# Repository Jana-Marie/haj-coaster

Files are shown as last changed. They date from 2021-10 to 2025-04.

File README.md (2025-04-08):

# haj-coaster

A sharky and colourful coaster glowing in pride for you~.

It consists of a stack of three circuit boards, sandwhiched together. There is a STM32F072, a LED driver and plenty LEDs on the baseboard, cutouts on the midboards to hide the components in, and a mask frontboard that shows the artwork. The LEDs are not all simple RGB ones, but a set of single color LEDs for the stars, carefully selected to represent the diversity in color on a night sky. For the girl on the left side, each LED spot consists of 5 single LEDs, RGB + Pink + Cyan, allowing one to expand the typical RGB range with opically pleasant cyan tones (for the shark and drink) and pink tones (e.g. for the skin, shark and drink).
There is also a NTC within the stack, I intended to change the sharks colour from cyan to pink following the coasters temperature. A warm drink would tint the shark pink, a cold one cyan. However, I never dared to place a drink on it, it's just to cute to hide it behind some glass or mug 🥺

<table>
  <tbody>
    <tr>
      <td colspan="2">
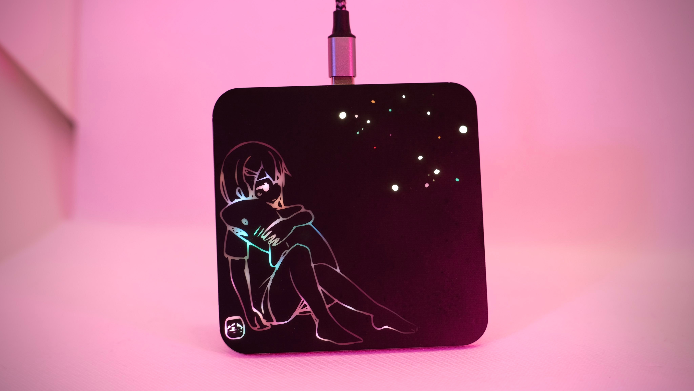
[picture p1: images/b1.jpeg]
        
      </td>
    </tr>
    <tr>
      <td>
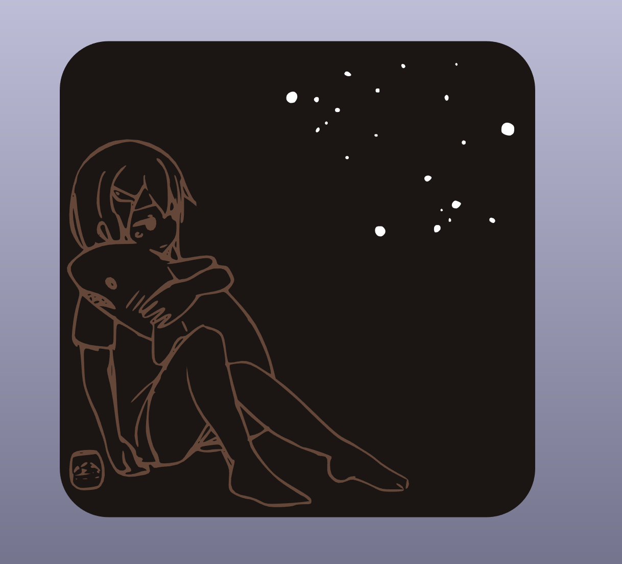
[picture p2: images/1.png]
        
      </td>
      <td>
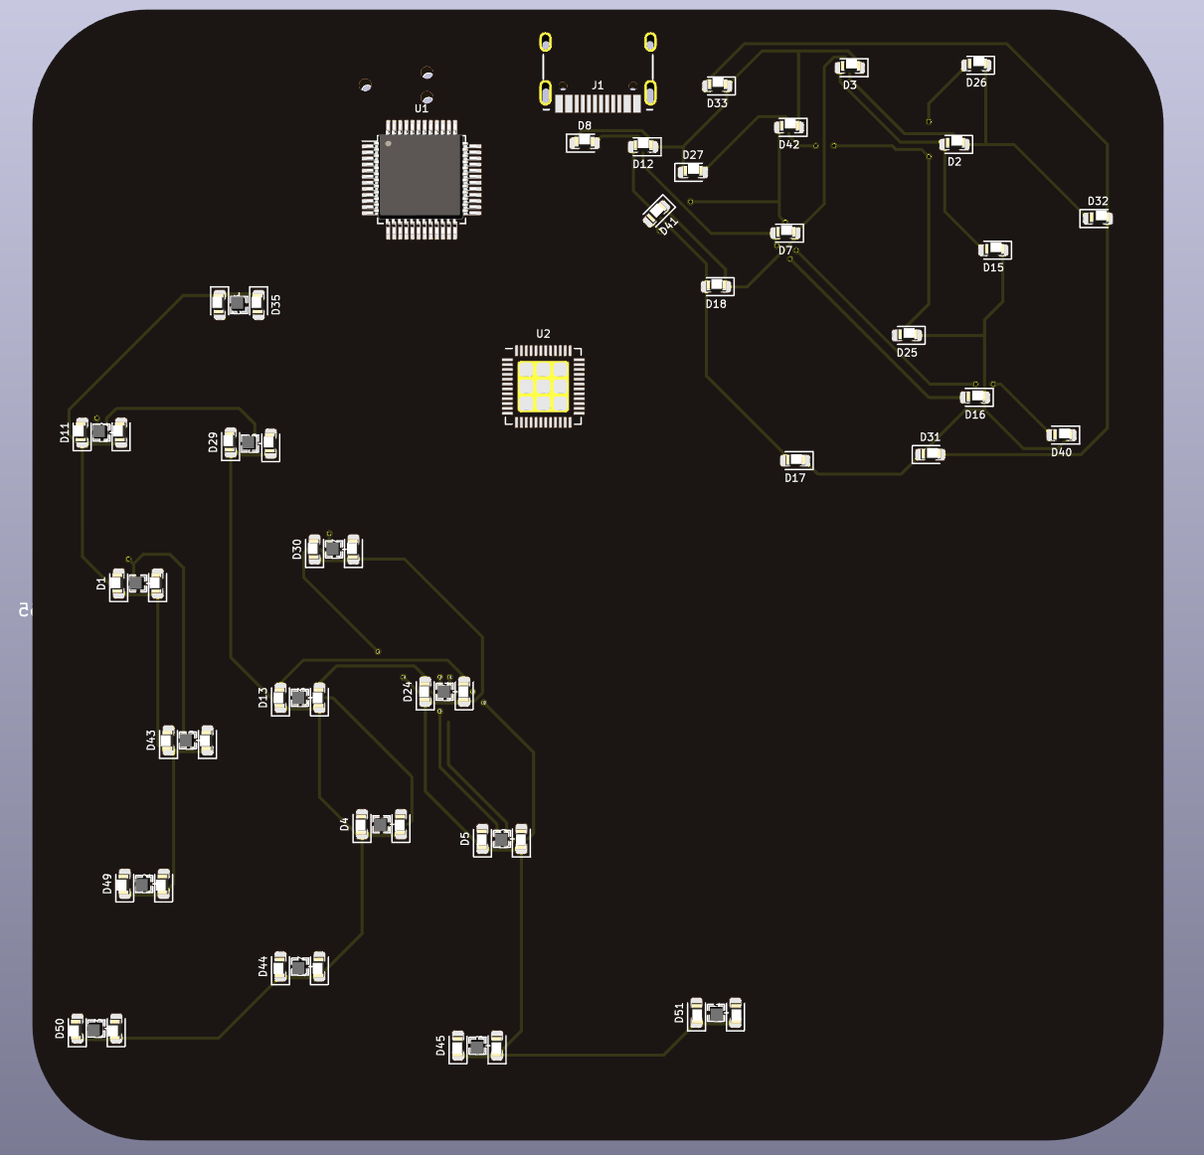
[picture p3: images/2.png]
        
      </td>
    </tr>
    <tr>
      <td colspan="2">
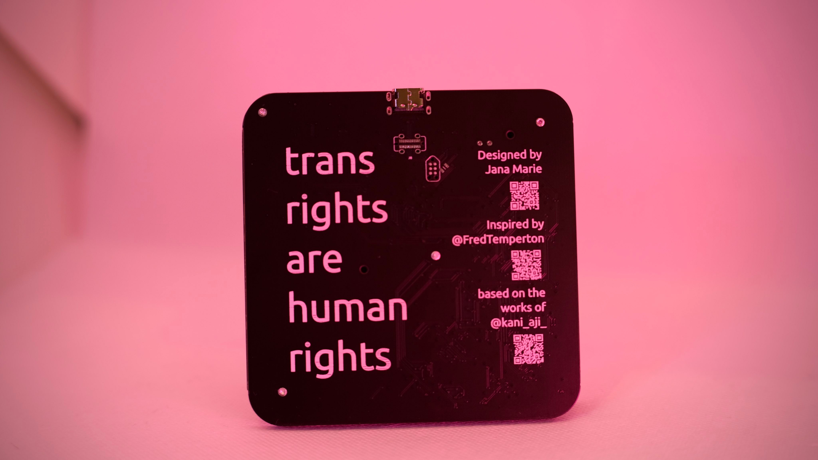
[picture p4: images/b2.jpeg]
        
      </td>
    </tr>
    <tr>
      <td>
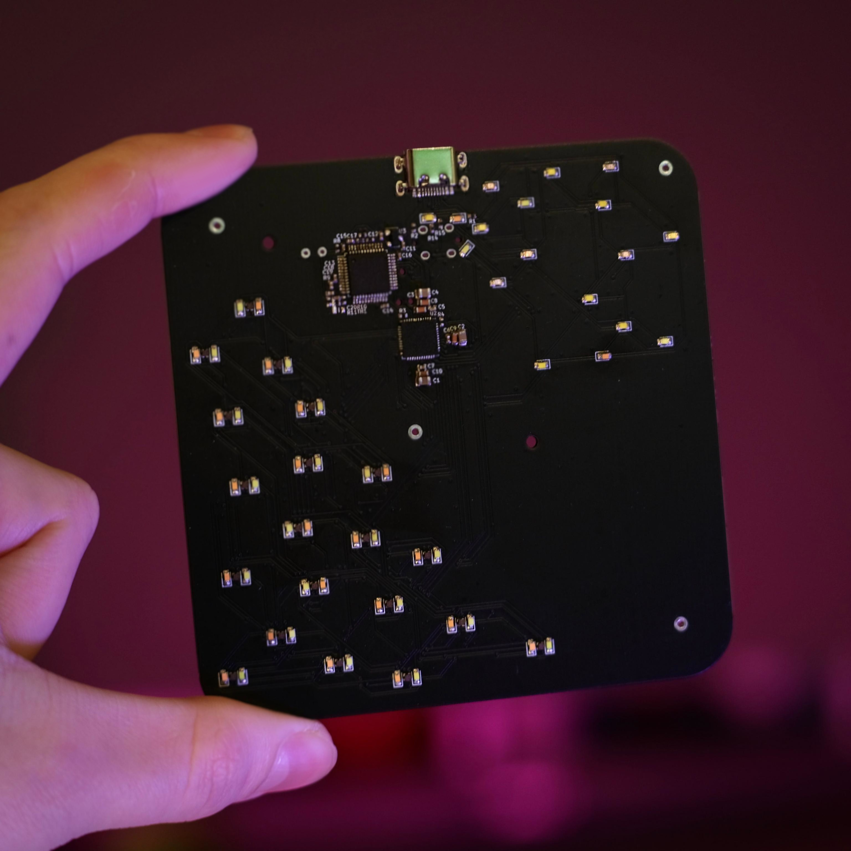
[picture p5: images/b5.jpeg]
        
      </td>
      <td>
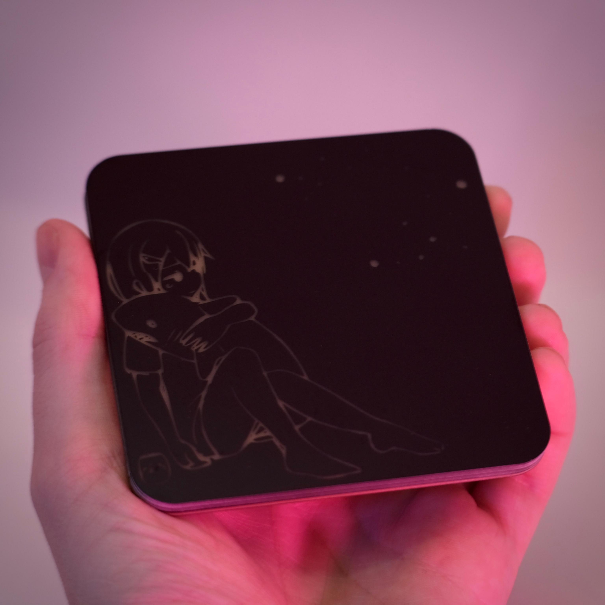
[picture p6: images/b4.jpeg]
        
      </td>
    </tr>
    <tr>
      <td colspan="2">
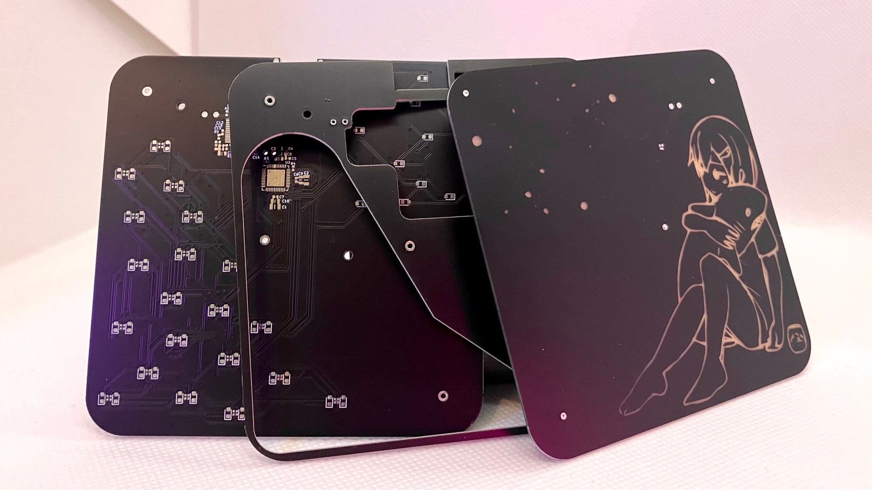
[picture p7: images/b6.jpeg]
        
      </td>
    </tr>
  </tbody>
</table>

---

### Schematic

(https://github.com/Jana-Marie/haj-coaster/blob/main/coaster_backboard/schematic.pdf)[schematic.pdf]

---

Thank you [かにあじ](https://void-aquarium.com/) for allowing me to use your fantastic artwork for this project! ありがとうございます!

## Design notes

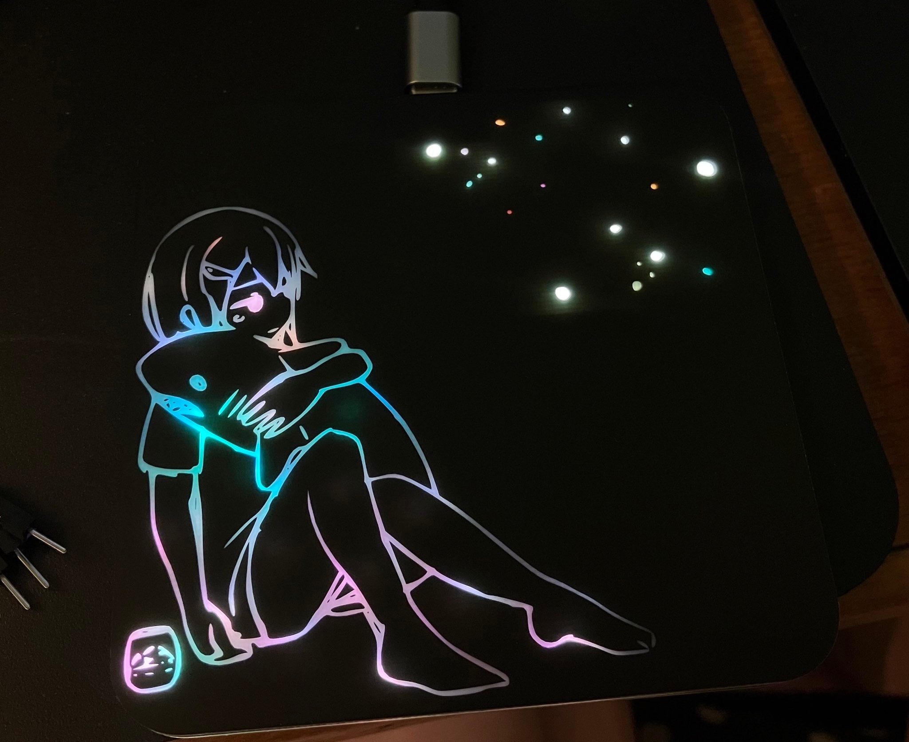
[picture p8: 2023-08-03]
images/f.jpeg

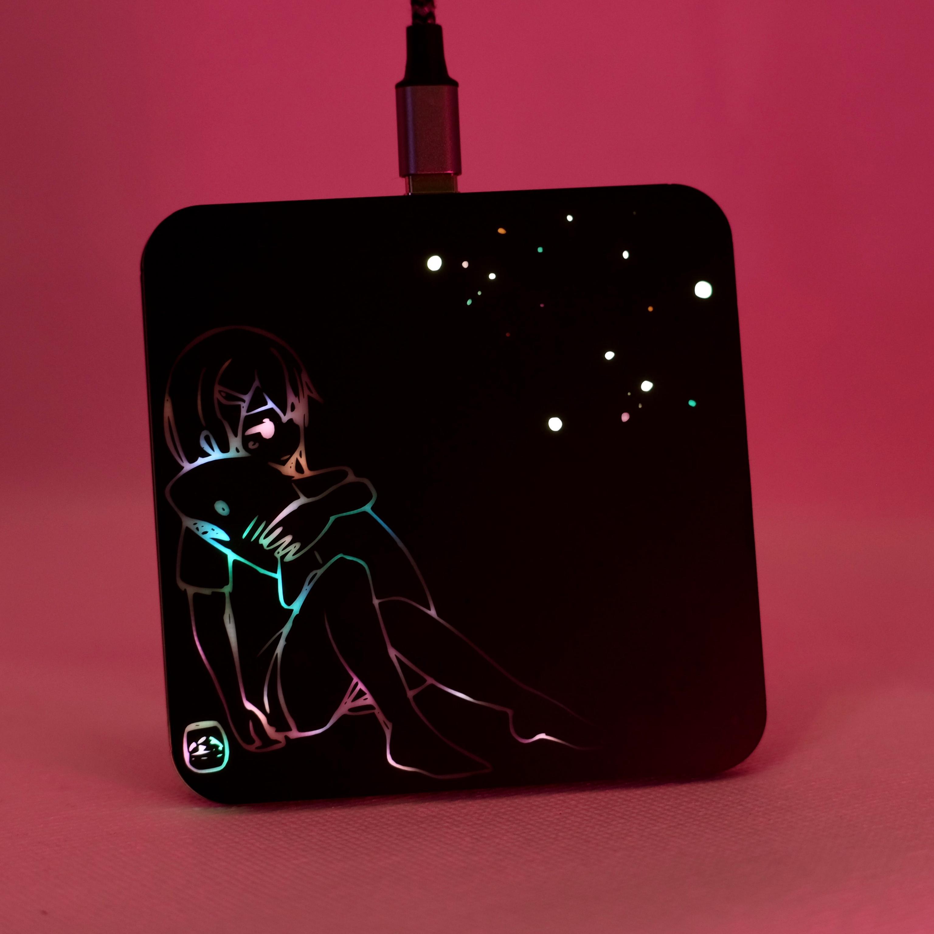
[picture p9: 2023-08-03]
images/b3.jpeg

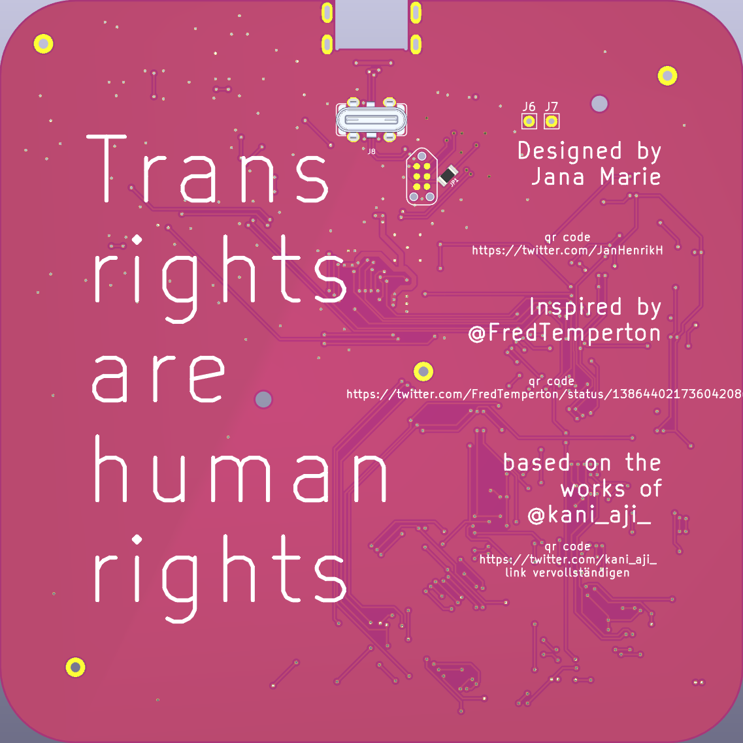
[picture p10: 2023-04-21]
coaster_backboard/assets/Screenshot from 2021-12-30 00-20-10.png

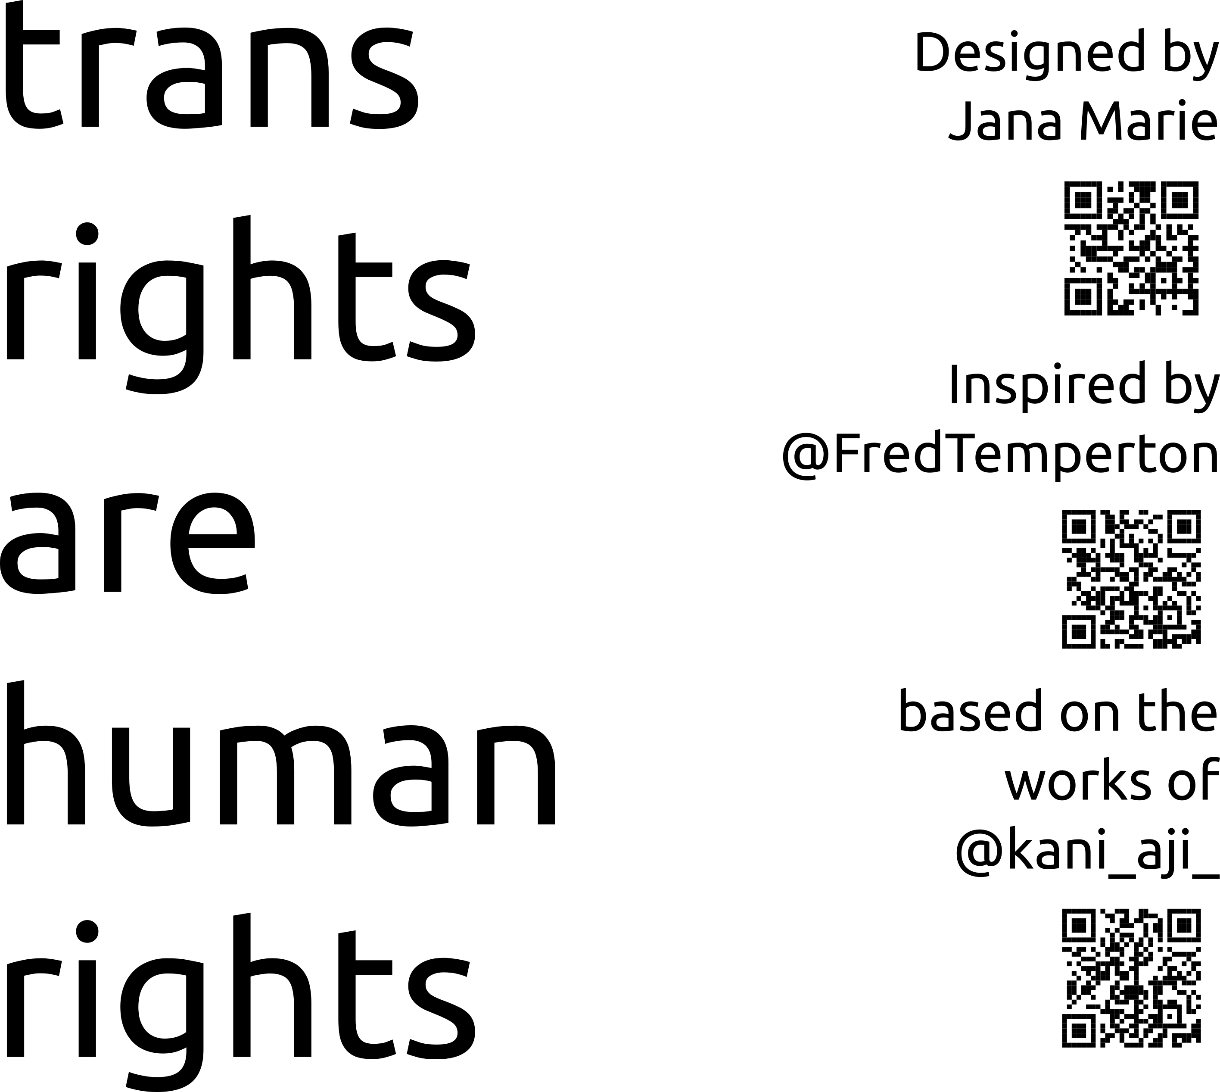
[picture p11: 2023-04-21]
coaster_backboard/assets/text_all.png

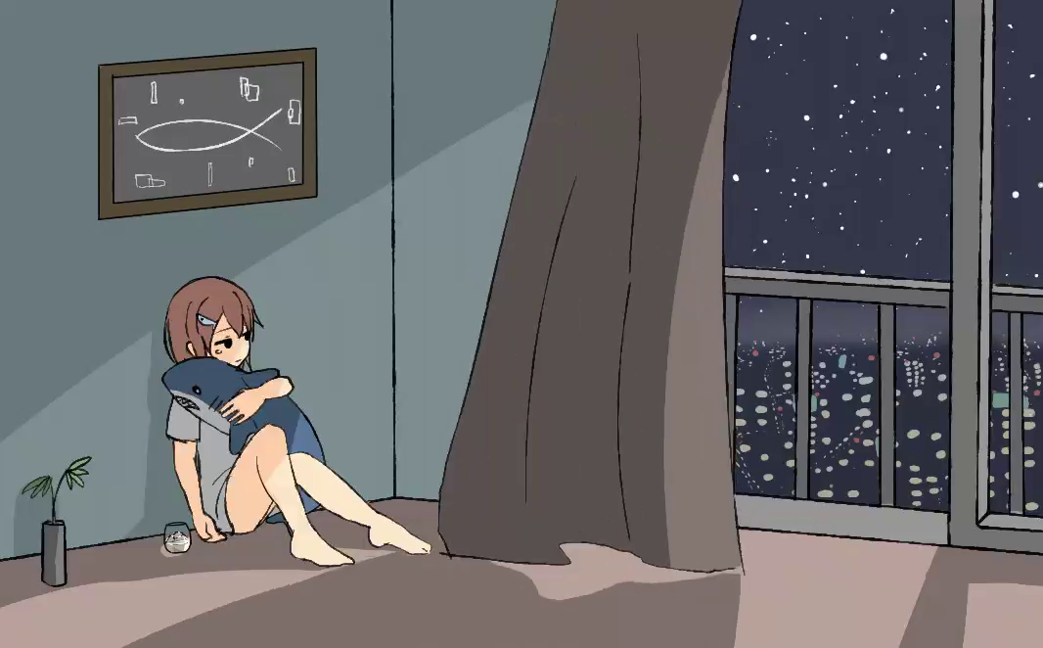
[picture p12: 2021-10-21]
artwork/out6.png

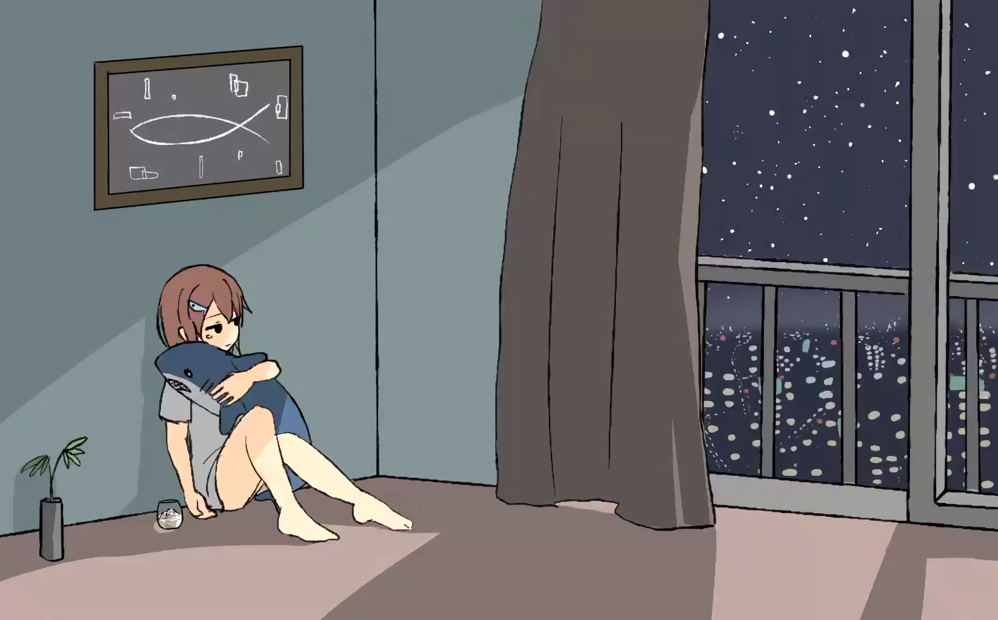
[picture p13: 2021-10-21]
artwork/out1_x4.png

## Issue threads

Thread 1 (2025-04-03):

Actual LEDs used

TyberiusPrime, 2025-04-03:
Gorgeous design, now you made me reinstall kicad after I had kicked the PCB habit for a good long time.

Currently struggling with picking the right LEDs over at JCLPCB.

Would you mind documenting which ones you used exactly?
I'm so unversed in kicad, it's only telling me the footprint and 'pink'.

Jana-Marie, 2025-04-08:
Hey, thank you! And I'm glad that you are back to KiCAD! :3

Let's see, something like this:

Pink: https://jlcpcb.com/partdetail/Xinglight-XL_1608UPC06/C2977076
Blue (Cyan): https://jlcpcb.com/partdetail/Meihua-MHT192WDTICE/C389522
RGB: https://jlcpcb.com/partdetail/169447-FC_B1010RGBTHG/C158099

These are all for the left side of the board, where the artwork of the girl and the shark is. For the starred sky I just used whatever I liked and I encourage you to do the same! Make it your board! :3

If you want a reference or copy my mostly random dispersion of colors, you can check this image for reference:

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

I think I used:

8 white LEDs: https://jlcpcb.com/partdetail/85434-NCD0603W1/C84265
3 Cyan LEDs: https://jlcpcb.com/partdetail/Meihua-MHT192WDTICE/C389522
2 amber/Yellow LEDs: https://jlcpcb.com/partdetail/Inolux-INS63AT5A/C5656657
                     or https://jlcpcb.com/partdetail/85438-NCD0603O1/C84269
2 pink LEDs: https://jlcpcb.com/partdetail/Xinglight-XL_1608UPC06/C2977076

But really, feel free to mix this up or even let them out on JLCs assembly and manually put them on the boards, make every board different. I really liked thinking about my favorite images of the Milky Way and thinking on how to replicate the lovely colours it can produce. This is also why I used discrete colours/wavelengths instead of RGB leds here.

Sorry for the late answer btw, hope you can get it manufactured!

Best
Jana

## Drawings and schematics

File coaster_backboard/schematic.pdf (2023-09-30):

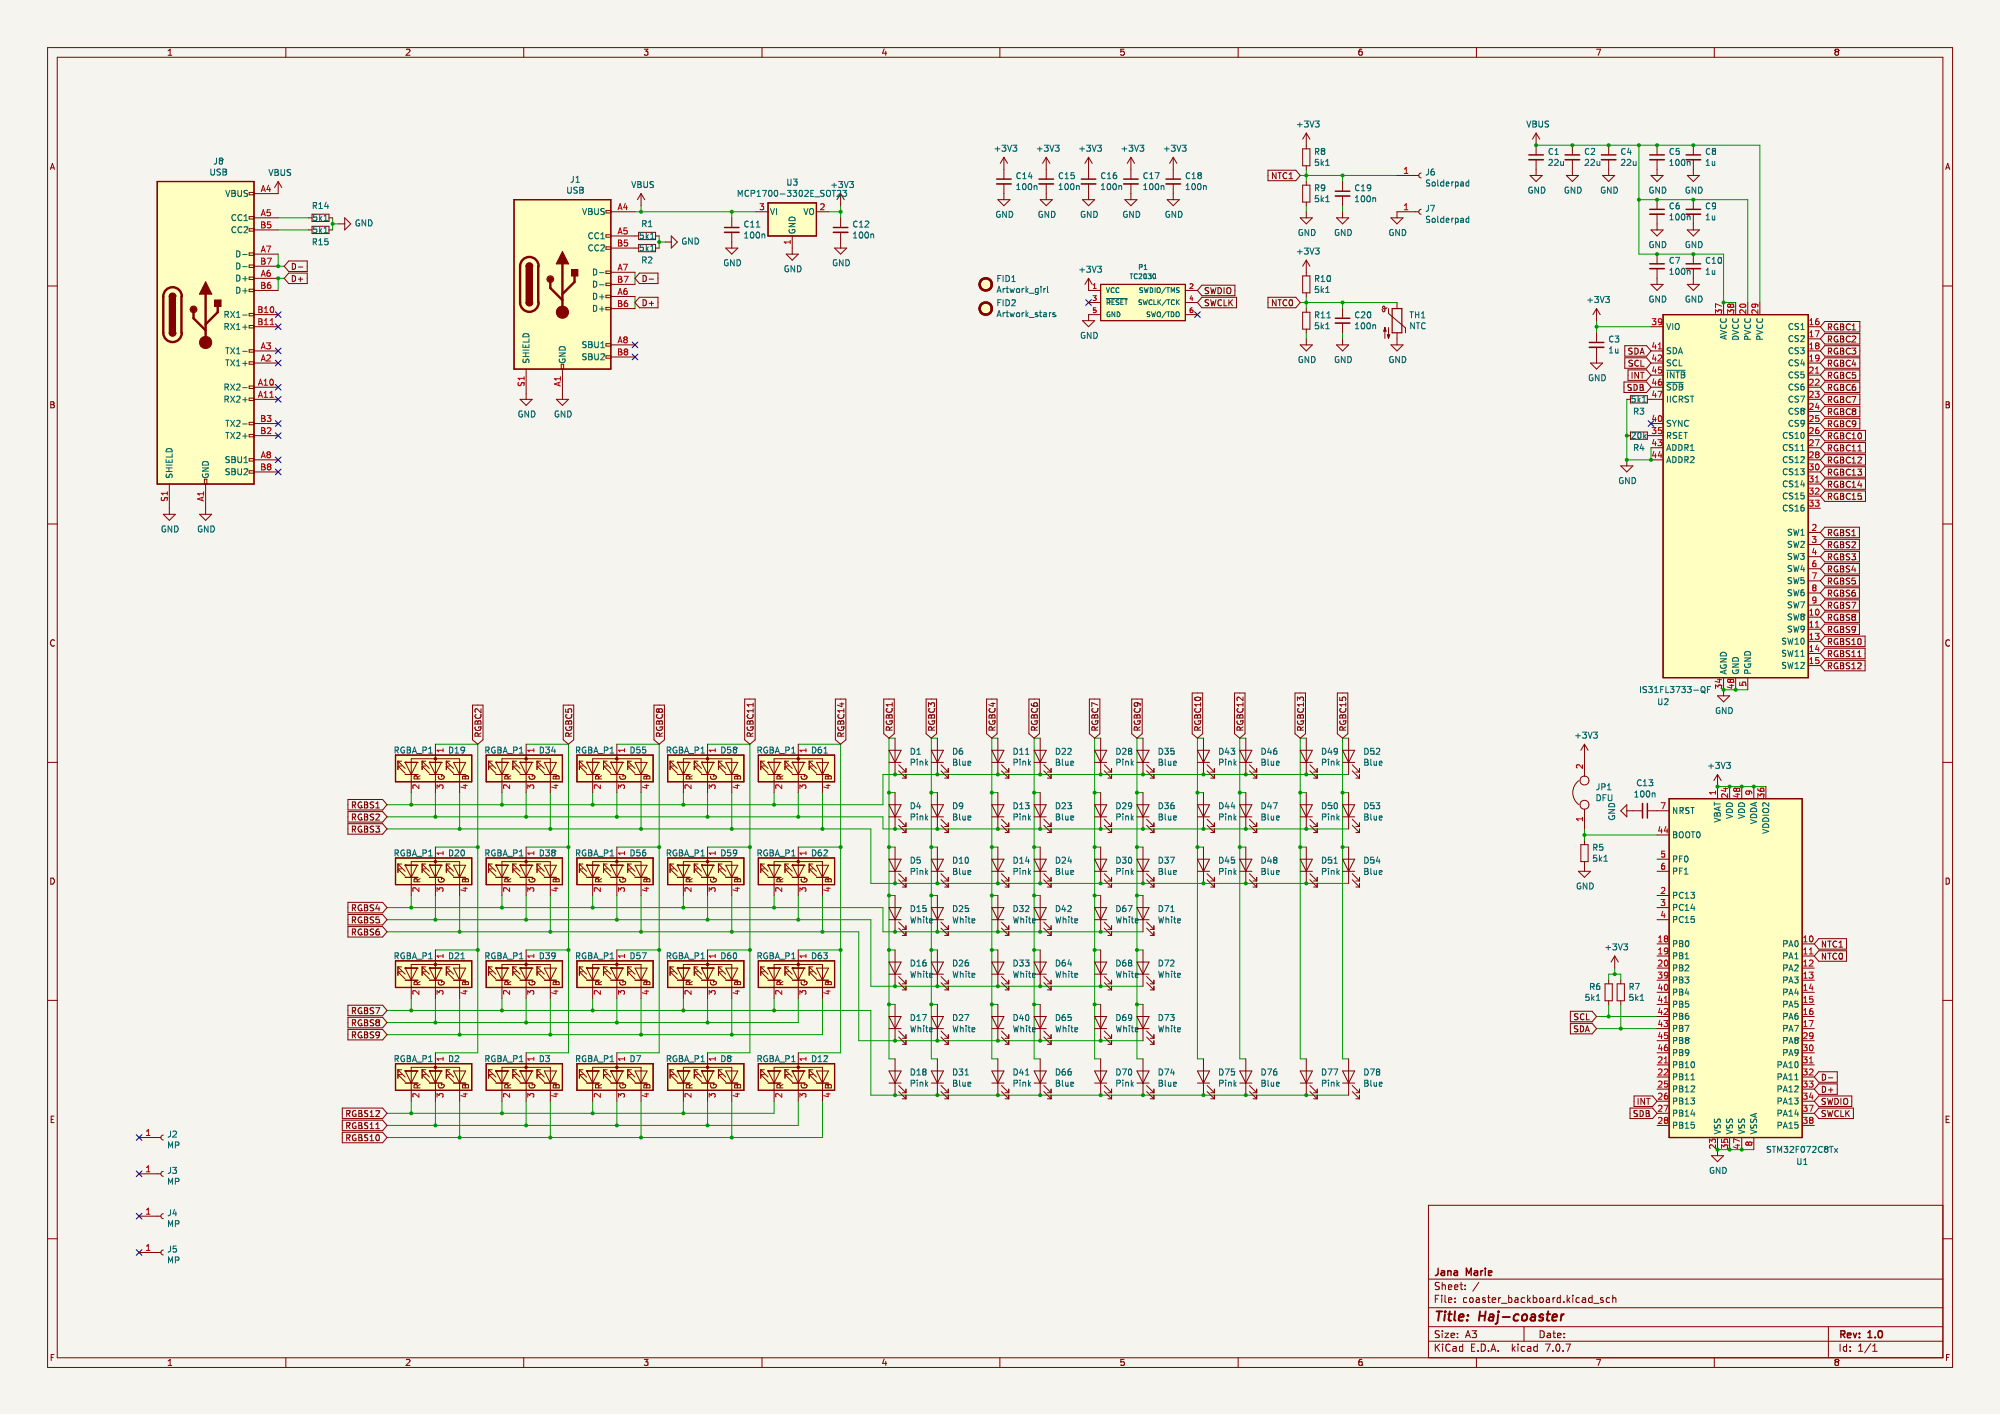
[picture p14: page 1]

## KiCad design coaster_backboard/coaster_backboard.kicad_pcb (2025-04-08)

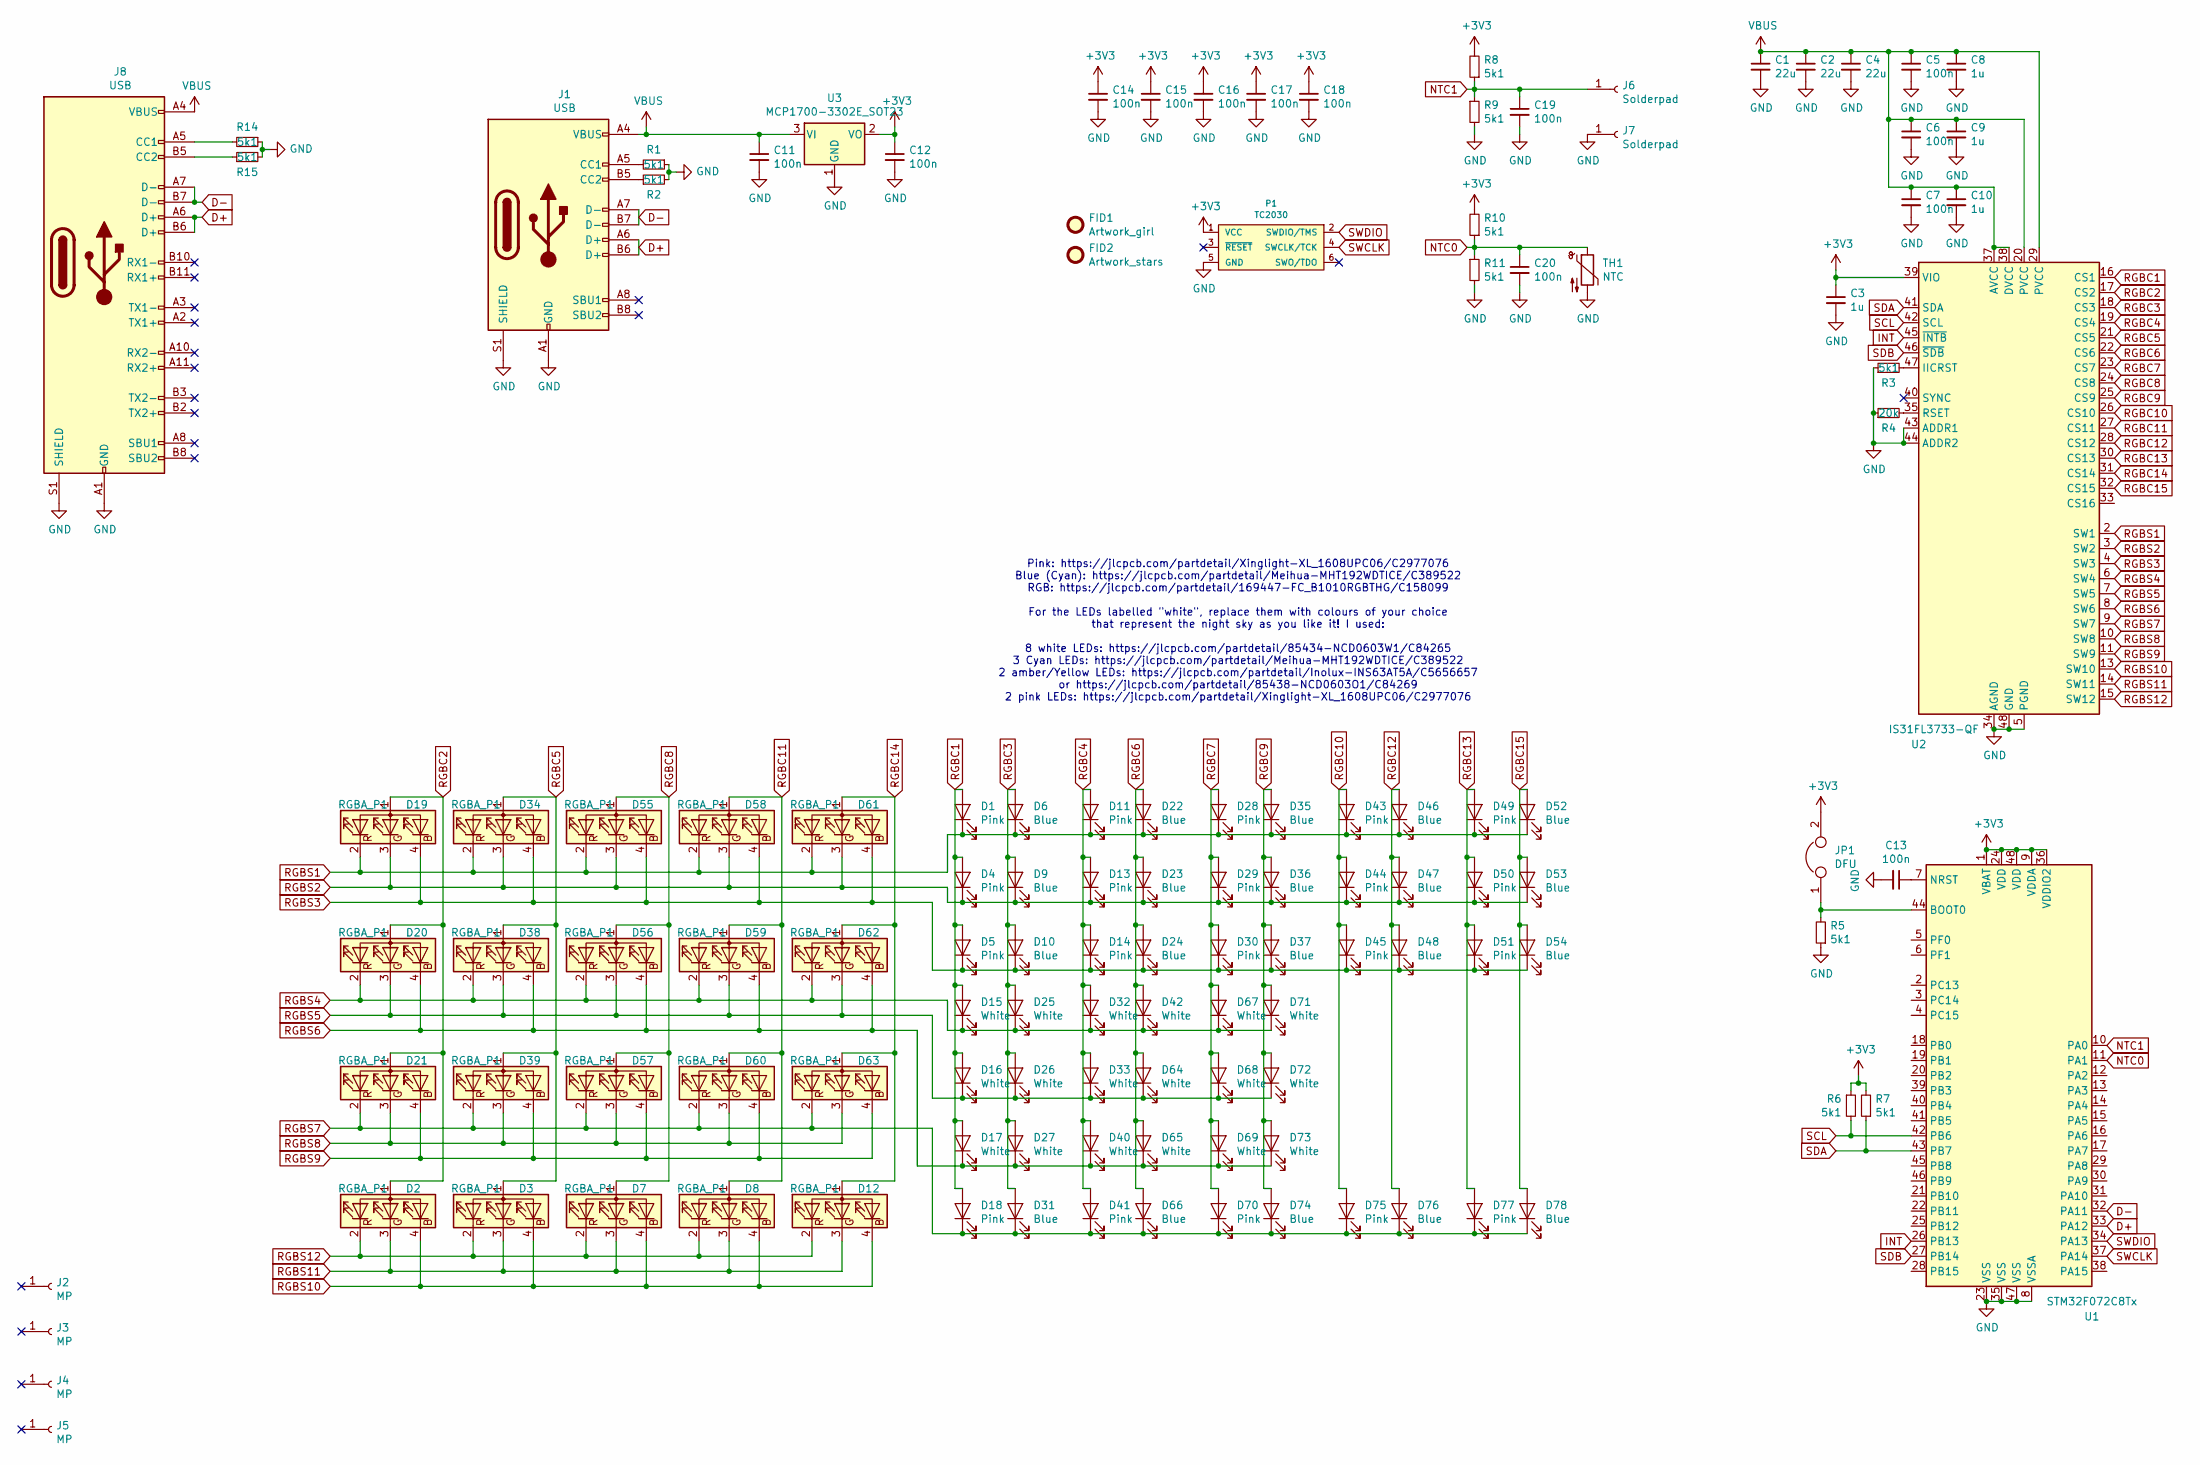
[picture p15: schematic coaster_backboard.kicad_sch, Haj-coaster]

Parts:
C1, C2, C4: 22u; C_0805
C3, C8, C9, C10: 1u; C_0603
C5, C6, C7, C11, C12, C13, C14, C15, C16, C17, C18, C19, C20: 100n; C_0402
D1, D4, D5, D11, D13, D14, D18, D28, D29, D30, D41, D43, D44, D45, D49, D50, D51, D70, D75, D77: Pink; LED_0603_1608Metric
D2, D3, D7, D8, D12, D19, D20, D21, D34, D38, D39, D55, D56, D57, D58, D59, D60, D61, D62, D63: RGBA_P1; FC-B1010RGBT-HG
D6, D9, D10, D22, D23, D24, D31, D35, D36, D37, D46, D47, D48, D52, D53, D54, D66, D74, D76, D78: Blue; LED_0603_1608Metric
D15, D16, D17, D25, D26, D27, D32, D33, D40, D42, D64, D65, D67, D68, D69, D71, D72, D73: White; LED_0603_1608Metric
FID1: Artwork_girl; shark_girl_kani_aji_
FID2: Artwork_stars; stars_kani_aji_
J1: USB; USB-C 16Pin InBoard
J2, J3, J4, J5: MP; Pin_D1.0mm_L10.0mm_LooseFit
J6, J7: Solderpad; Pin_D0.7mm_L6.5mm_W1.8mm_FlatFork
J8: USB; 918-418K2022Y40004
JP1: DFU; R_0805
P1: TC2030
R1, R2, R3, R5, R6, R7, R8, R9, R10, R11, R14, R15: 5k1; R_0402
R4: 20k; R_0402
TH1: NTC; R_0603
U1: STM32F072C8Tx; LQFP-48_7x7mm_P0.5mm
U2: IS31FL3733-QF; QFN-48-1EP_6x6mm_P0.4mm_EP4.2x4.2mm
U3: MCP1700-3302E_SOT23; SOT-23

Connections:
+3V3: C3.1, C12.1, C14.1, C15.1, C16.1, C17.1, C18.1, JP1.2, P1.1 (VCC), R6.1, R7.2, R8.2, R10.2, U1.1 (VBAT), U1.9 (VDDA), U1.24 (VDD), U1.36 (VDDIO2), U1.48 (VDD), U2.39 (VIO), U3.2 (VO)
D+: J1.A6 (D+), J1.B6 (D+), J8.A6 (D+), J8.B6 (D+), U1.33 (PA12)
D-: J1.A7 (D-), J1.B7 (D-), J8.A7 (D-), J8.B7 (D-), U1.32 (PA11)
GND: C1.2, C2.2, C3.2, C4.2, C5.2, C6.2, C7.2, C8.2, C9.2, C10.2, C11.2, C12.2, C13.2, C14.2, C15.2, C16.2, C17.2, C18.2, C19.2, C20.2, J1.A1 (GND), J1.A12 (GND), J1.B1 (GND), J1.B12 (GND), J1.S1 (SHIELD), J7.1, J8.A1 (GND), J8.A12 (GND), J8.B1 (GND), J8.B12 (GND), J8.S1 (SHIELD), P1.5 (GND), R1.1, R2.2, R3.1, R4.1, R5.1, R9.2, R11.2, R14.1, R15.2, TH1.2, U1.8 (VSSA), U1.23 (VSS), U1.35 (VSS), U1.47 (VSS), U2.5 (PGND), U2.12 (PGND), U2.34 (AGND), U2.43 (ADDR1), U2.44 (ADDR2), U2.48 (GND), U2.49 (GND), U3.1 (GND)
INT: U1.26 (PB13), U2.45 (~INTB)
NTC0: C20.1, R10.1, R11.1, TH1.1, U1.11 (PA1)
NTC1: C19.1, J6.1, R8.1, R9.1, U1.10 (PA0)
unnamed: C13.1, U1.7 (NRST)
unnamed: J1.A5 (CC1), R1.2
unnamed: J1.B5 (CC2), R2.1
unnamed: J8.A5 (CC1), R14.2
unnamed: J8.B5 (CC2), R15.1
unnamed: JP1.1, R5.2, U1.44 (BOOT0)
unnamed: R3.2, U2.47 (IICRST)
unnamed: R4.2, U2.35 (RSET)
RGBC1: D1.2 (A), D4.2 (A), D5.2 (A), D15.2 (A), D16.2 (A), D17.2 (A), D18.2 (A), U2.16 (CS1)
RGBC2: D2.1 (A), D19.1 (A), D20.1 (A), D21.1 (A), U2.17 (CS2)
RGBC3: D6.2 (A), D9.2 (A), D10.2 (A), D25.2 (A), D26.2 (A), D27.2 (A), D31.2 (A), U2.18 (CS3)
RGBC4: D11.2 (A), D13.2 (A), D14.2 (A), D32.2 (A), D33.2 (A), D40.2 (A), D41.2 (A), U2.19 (CS4)
RGBC5: D3.1 (A), D34.1 (A), D38.1 (A), D39.1 (A), U2.21 (CS5)
RGBC6: D22.2 (A), D23.2 (A), D24.2 (A), D42.2 (A), D64.2 (A), D65.2 (A), D66.2 (A), U2.22 (CS6)
RGBC7: D28.2 (A), D29.2 (A), D30.2 (A), D67.2 (A), D68.2 (A), D69.2 (A), D70.2 (A), U2.23 (CS7)
RGBC8: D7.1 (A), D55.1 (A), D56.1 (A), D57.1 (A), U2.24 (CS8)
RGBC9: D35.2 (A), D36.2 (A), D37.2 (A), D71.2 (A), D72.2 (A), D73.2 (A), D74.2 (A), U2.25 (CS9)
RGBC10: D43.2 (A), D44.2 (A), D45.2 (A), D75.2 (A), U2.26 (CS10)
RGBC11: D8.1 (A), D58.1 (A), D59.1 (A), D60.1 (A), U2.27 (CS11)
RGBC12: D46.2 (A), D47.2 (A), D48.2 (A), D76.2 (A), U2.28 (CS12)
RGBC13: D49.2 (A), D50.2 (A), D51.2 (A), D77.2 (A), U2.30 (CS13)
RGBC14: D12.1 (A), D61.1 (A), D62.1 (A), D63.1 (A), U2.31 (CS14)
RGBC15: D52.2 (A), D53.2 (A), D54.2 (A), D78.2 (A), U2.32 (CS15)
RGBS1: D1.1 (K), D6.1 (K), D11.1 (K), D19.2 (RK), D22.1 (K), D28.1 (K), D34.2 (RK), D35.1 (K), D43.1 (K), D46.1 (K), D49.1 (K), D52.1 (K), D55.2 (RK), D58.2 (RK), D61.2 (RK), U2.2 (SW1)
RGBS2: D4.1 (K), D9.1 (K), D13.1 (K), D19.3 (GK), D23.1 (K), D29.1 (K), D34.3 (GK), D36.1 (K), D44.1 (K), D47.1 (K), D50.1 (K), D53.1 (K), D55.3 (GK), D58.3 (GK), D61.3 (GK), U2.3 (SW2)
RGBS3: D5.1 (K), D10.1 (K), D14.1 (K), D19.4 (BK), D24.1 (K), D30.1 (K), D34.4 (BK), D37.1 (K), D45.1 (K), D48.1 (K), D51.1 (K), D54.1 (K), D55.4 (BK), D58.4 (BK), D61.4 (BK), U2.4 (SW3)
RGBS4: D15.1 (K), D20.2 (RK), D25.1 (K), D32.1 (K), D38.2 (RK), D42.1 (K), D56.2 (RK), D59.2 (RK), D62.2 (RK), D67.1 (K), D71.1 (K), U2.6 (SW4)
RGBS5: D16.1 (K), D20.3 (GK), D26.1 (K), D33.1 (K), D38.3 (GK), D56.3 (GK), D59.3 (GK), D62.3 (GK), D64.1 (K), D68.1 (K), D72.1 (K), U2.7 (SW5)
RGBS6: D17.1 (K), D20.4 (BK), D27.1 (K), D38.4 (BK), D40.1 (K), D56.4 (BK), D59.4 (BK), D62.4 (BK), D65.1 (K), D69.1 (K), D73.1 (K), U2.8 (SW6)
RGBS7: D18.1 (K), D21.2 (RK), D31.1 (K), D39.2 (RK), D41.1 (K), D57.2 (RK), D60.2 (RK), D63.2 (RK), D66.1 (K), D70.1 (K), D74.1 (K), D75.1 (K), D76.1 (K), D77.1 (K), D78.1 (K), U2.9 (SW7)
RGBS8: D21.3 (GK), D39.3 (GK), D57.3 (GK), D60.3 (GK), D63.3 (GK), U2.10 (SW8)
RGBS9: D21.4 (BK), D39.4 (BK), D57.4 (BK), D60.4 (BK), D63.4 (BK), U2.11 (SW9)
RGBS10: D2.4 (BK), D3.4 (BK), D7.4 (BK), D8.4 (BK), D12.4 (BK), U2.13 (SW10)
RGBS11: D2.3 (GK), D3.3 (GK), D7.3 (GK), D8.3 (GK), D12.3 (GK), U2.14 (SW11)
RGBS12: D2.2 (RK), D3.2 (RK), D7.2 (RK), D8.2 (RK), D12.2 (RK), U2.15 (SW12)
SCL: R6.2, U1.42 (PB6), U2.42 (SCL)
SDA: R7.1, U1.43 (PB7), U2.41 (SDA)
SDB: U1.27 (PB14), U2.46 (~SDB)
SWCLK: P1.4 (SWCLK/TCK), U1.37 (PA14)
SWDIO: P1.2 (SWDIO/TMS), U1.34 (PA13)
VBUS: C1.1, C2.1, C4.1, C5.1, C6.1, C7.1, C8.1, C9.1, C10.1, C11.1, J1.A4 (VBUS), J1.A9 (VBUS), J1.B4 (VBUS), J1.B9 (VBUS), J8.A4 (VBUS), J8.A9 (VBUS), J8.B4 (VBUS), J8.B9 (VBUS), U2.20 (PVCC), U2.29 (PVCC), U2.37 (AVCC), U2.38 (DVCC), U3.3 (VI)

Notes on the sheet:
Pink: https://jlcpcb.com/partdetail/Xinglight-XL_1608UPC06/C2977076 Blue (Cyan): https://jlcpcb.com/partdetail/Meihua-MHT192WDTICE/C389522 RGB: https://jlcpcb.com/partdetail/169447-FC_B1010RGBTHG/C158099 For the LEDs labelled "white", replace them with colours of your choice that represent the nigh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

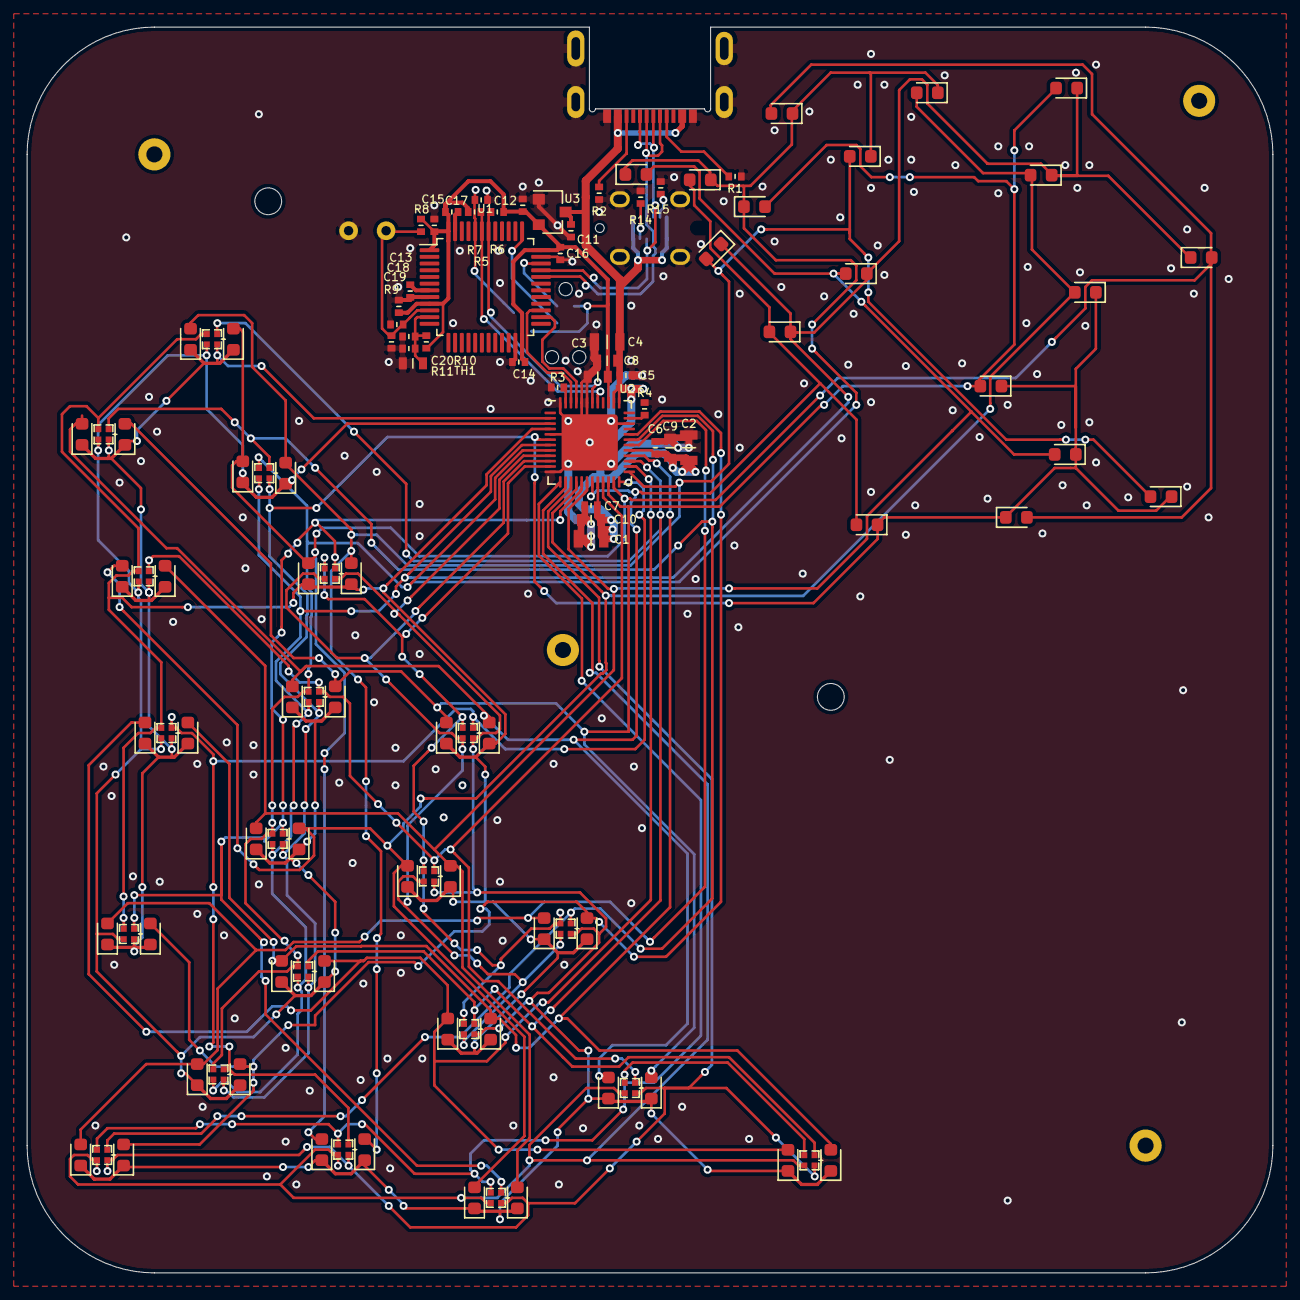
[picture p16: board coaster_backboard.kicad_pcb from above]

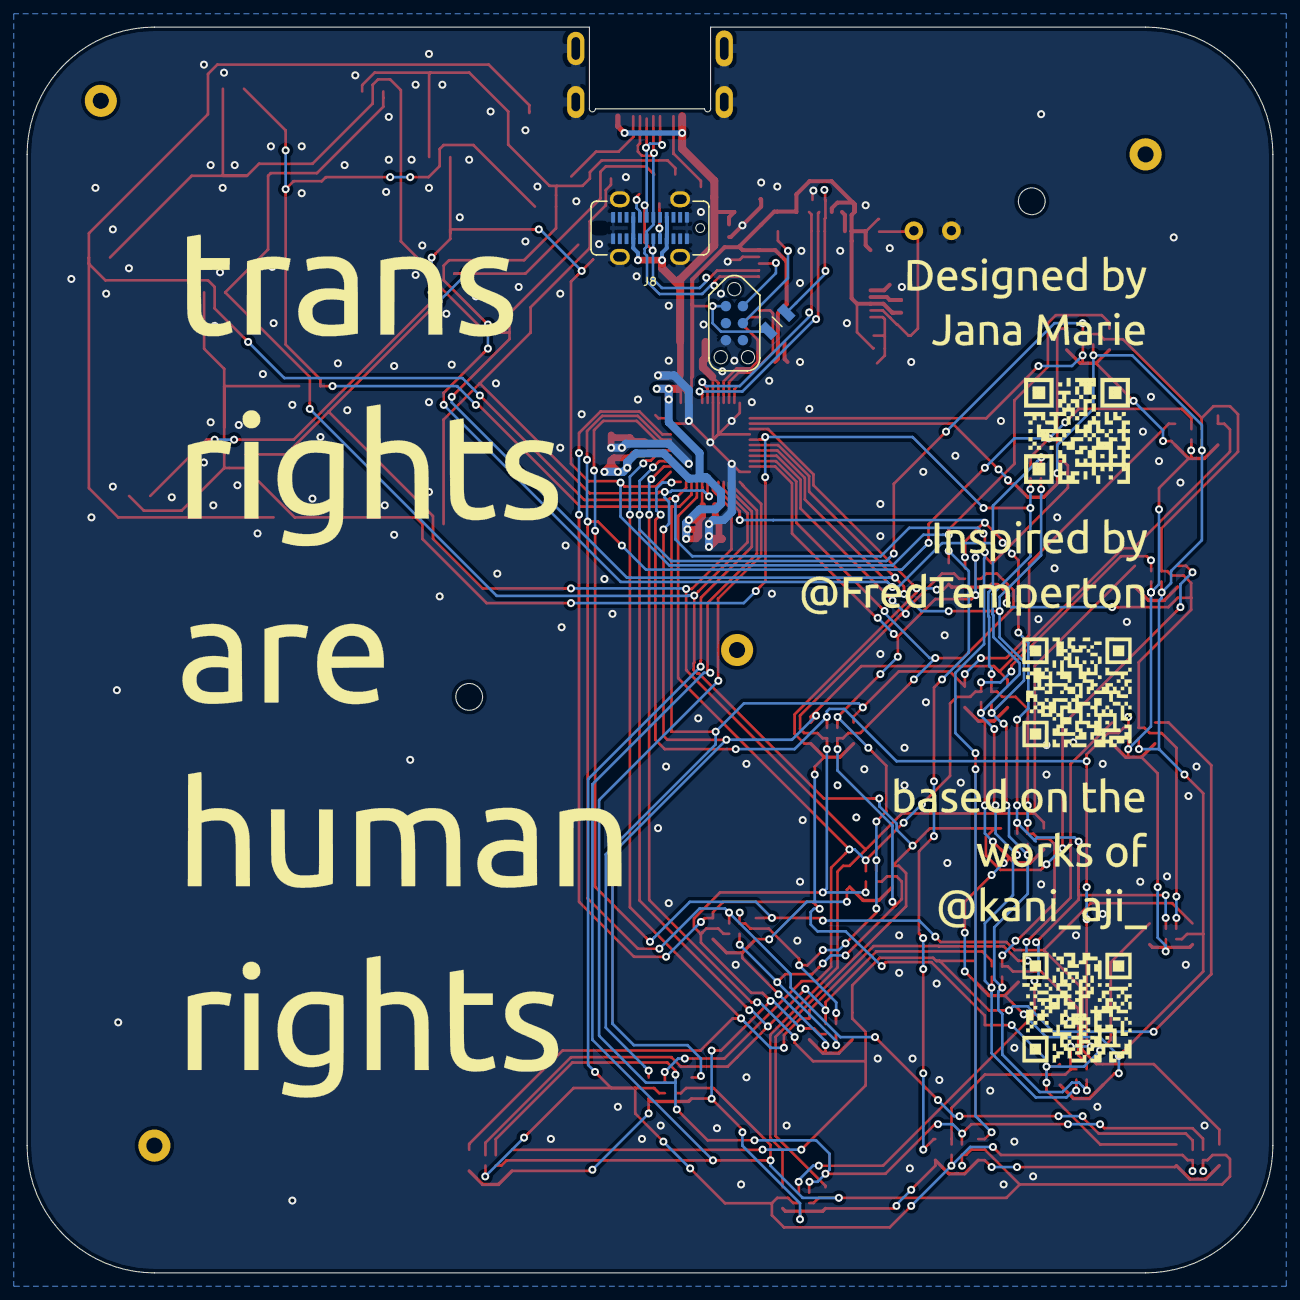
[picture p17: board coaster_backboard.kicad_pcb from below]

Board: 2 copper layers, 93.0 x 93.0 mm, 127 parts (5 on the bottom side), 48 nets.

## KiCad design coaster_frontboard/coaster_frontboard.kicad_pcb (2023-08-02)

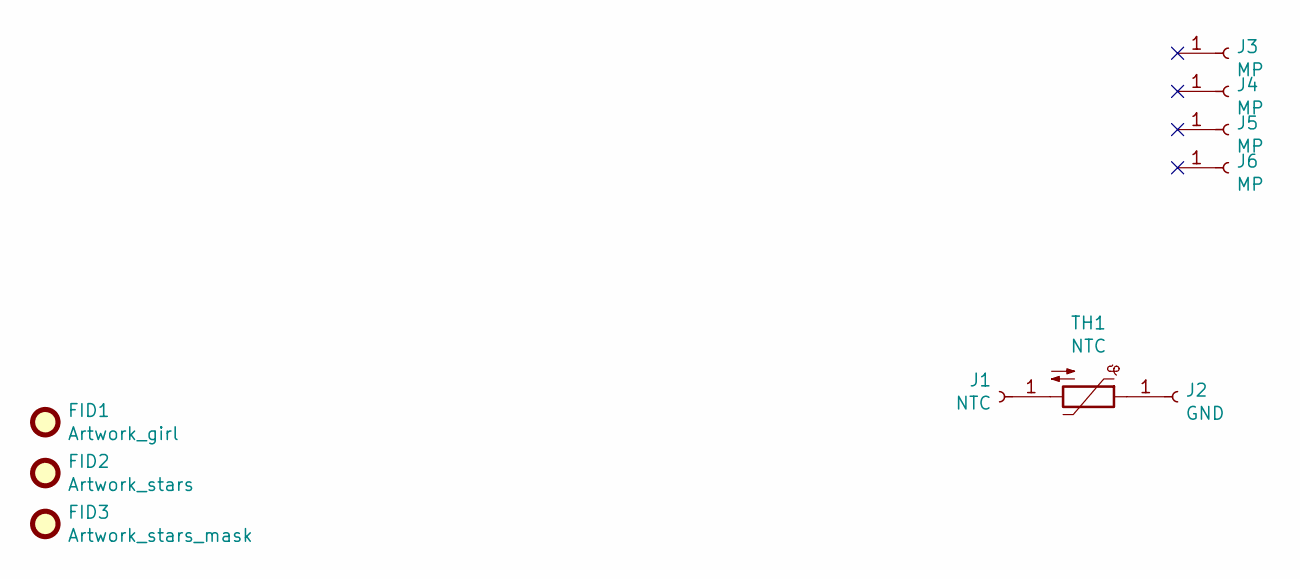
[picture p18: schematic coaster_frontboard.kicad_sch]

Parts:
FID1: Artwork_girl; shark_girl_kani_aji_
FID2: Artwork_stars; stars_kani_aji_
FID3: Artwork_stars_mask; stars_mask_kani_aji_
J1: NTC; TestPoint_Pad_D1.5mm
J2: GND; TestPoint_Pad_D1.5mm
J3, J4, J5, J6: MP; TestPoint_Pad_D1.5mm
TH1: NTC; R_0402

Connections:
unnamed: J1.1, TH1.2
unnamed: J2.1, TH1.1

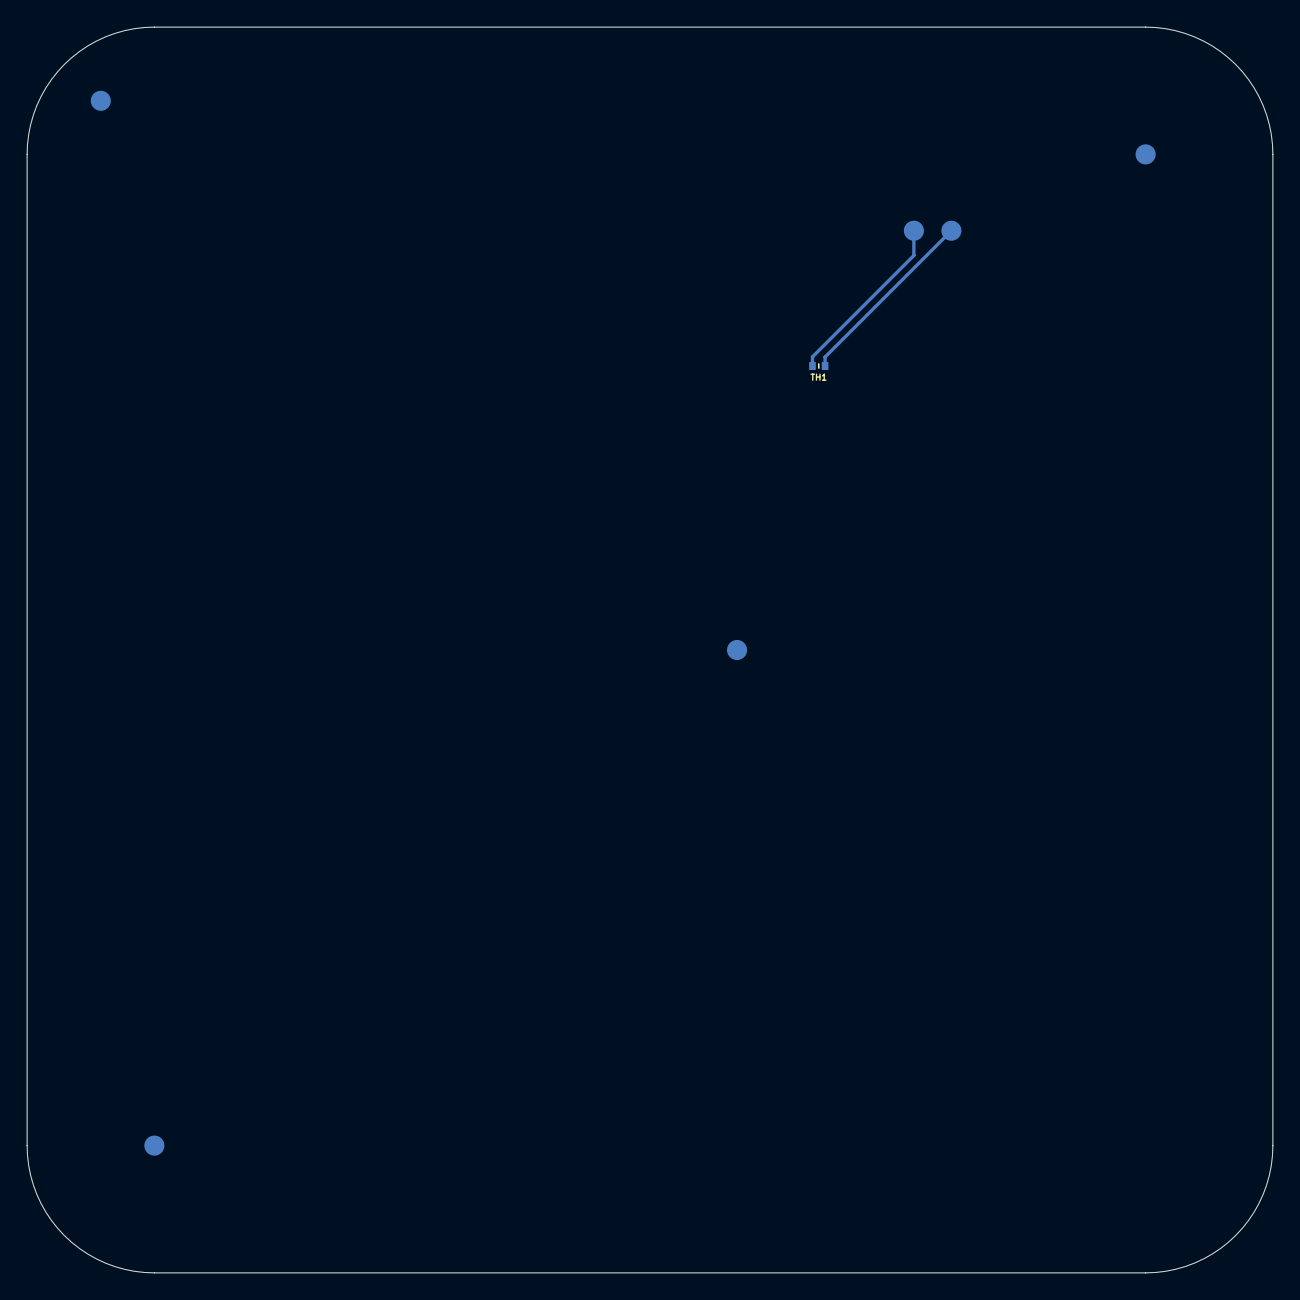
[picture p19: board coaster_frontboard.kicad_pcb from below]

Board: 2 copper layers, 93.0 x 93.0 mm, 10 parts (7 on the bottom side), 2 nets.

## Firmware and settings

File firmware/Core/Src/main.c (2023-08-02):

#include "main.h"
#include "usb_device.h"
#include "is31fl3733.h"

#define CLAMP(x, low, high) (((x) > (high)) ? (high) : (((x) < (low)) ? (low) : (x)))
#define ABS(x) ((x) < 0 ? -(x) : (x))

ADC_HandleTypeDef hadc;
DMA_HandleTypeDef hdma_adc;

I2C_HandleTypeDef hi2c1;
DMA_HandleTypeDef hdma_i2c1_tx;
DMA_HandleTypeDef hdma_i2c1_rx;

TIM_HandleTypeDef htim1;

void SystemClock_Config(void);
static void MX_GPIO_Init(void);
static void MX_DMA_Init(void);
static void MX_I2C1_Init(void);
static void MX_ADC_Init(void);
static void MX_TIM1_Init(void);
void rng(void);

uint16_t adc[3];
uint8_t noise8;
uint16_t noise16;
uint32_t noise32 = 37;

// Map of all Stars
uint8_t mappingStars[18] = {0x30, 0x32, 0x33, 0x35, 0x36, 0x38,
                            0x40, 0x42, 0x43, 0x45, 0x46, 0x48,
                            0x50, 0x52, 0x53, 0x55, 0x56, 0x58};
// Index of mappingStars
uint8_t subMappingStarsRed = 0x08;
uint8_t subMappingStarsGreen = 0x09;
uint8_t subMappingStarsYellow[2] = {0x00, 0x10};
uint8_t subMappingStarsPink[3] = {0x0E, 0x07, 0x04};
uint8_t subMappingStarsCyan[3] = {0x0B, 0x11, 0x05};
uint8_t subMappingStarsWhite[8] = {0x01, 0x02, 0x03, 0x06, 0x0A, 0x0C, 0x0D, 0x0F};

// Map of all RGB LEDs and their adjacent Cyan and Pink ones
uint8_t mappingR[20] = {0x01, 0x04, 0x07, 0x0A, 0x0D,
                        0x31, 0x34, 0x37, 0x3A, 0x3D,
                        0x61, 0x64, 0x67, 0x6A, 0x6D,
                        0xB1, 0xB4, 0xB7, 0xBA, 0xBD};
uint8_t mappingG[20] = {0x11, 0x14, 0x17, 0x1A, 0x1D,
                        0x41, 0x44, 0x47, 0x4A, 0x4D,
                        0x71, 0x74, 0x77, 0x7A, 0x7D,
                        0xA1, 0xA4, 0xA7, 0xAA, 0xAD};
uint8_t mappingB[20] = {0x21, 0x24, 0x27, 0x2A, 0x2D,
                        0x51, 0x54, 0x57, 0x5A, 0x5D,
                        0x81, 0x84, 0x87, 0x8A, 0x8D,
                        0x91, 0x94, 0x97, 0x9A, 0x9D};

uint8_t mappingP[20] = {0x0C, 0x00, 0x09, 0x06, 0x03,
                        0x10, 0x13, 0x1C, 0x19, 0x16,
                        0x26, 0x20, 0x23, 0x29, 0x2C,
                        0x60, 0x63, 0x66, 0x69, 0x6C};
uint8_t mappingC[20] = {0x0E, 0x02, 0x0B, 0x08, 0x05,
                        0x12, 0x15, 0x1E, 0x1B, 0x18,
                        0x28, 0x22, 0x25, 0x2B, 0x2E,
                        0x62, 0x65, 0x68, 0x6B, 0x6E};

// Index of all RGB + adjacent LEDs
uint8_t subMappingGlass = 0x13;
uint8_t subMappingShark[4] = {0x01, 0x02, 0x05, 0x0C};
uint8_t subMappingHead[4] = {0x04, 0x03, 0x09, 0x0A};
uint8_t subMappingArms[3] = {0x00, 0x07, 0x06};
uint8_t subMappingLegs[8] = {0x08, 0x11, 0x0B, 0x0D, 0x0F, 0x0E, 0x10, 0x12};
uint8_t subMappingBody[4+3+8] = { 0 };

// Additional maps
uint8_t gammaMap[256] = { 0, 1, 2, 3, 4, 5, 6, 7, 8, 10, 12, 14, 16, 18, 20, 22, 
                          24, 26, 29, 32, 35, 38, 41, 44, 47, 50, 53, 57, 61, 
                          65, 69, 73, 77, 81, 85, 89, 94, 99, 104, 109, 114, 119, 
                          124, 129, 134, 140, 146, 152, 158, 164, 170, 176, 
                          182, 188, 195, 202, 209, 216, 223, 230, 237, 244, 251, 255};

int8_t starSparkleMap[18];
uint8_t starSparkleNormalMap[18];
uint8_t starBaseBrightWhite = 56;
uint8_t starBaseBrightCyan = 20;
uint8_t starBaseBrightPink = 15;
uint8_t starBaseBrightYellow = 30;
uint8_t starBaseBrightRed = 10;
uint8_t starBaseBrightGreen = 30;

// Framebuffer
uint8_t pwmBuf[pwmLen];
uint8_t heartbeat;

int main(void)
{
  HAL_Init();
  SystemClock_Config();
  MX_GPIO_Init();
  MX_DMA_Init();
  MX_I2C1_Init();
  MX_ADC_Init();
  MX_TIM1_Init();
  MX_USB_DEVICE_Init();
  HAL_GPIO_WritePin(EN_GPIO_Port, EN_Pin, 1);
  HAL_ADC_Start_DMA(&hadc, (uint32_t *) &adc[0], 3);
  HAL_TIM_Base_Start_IT(&htim1);

  ISSI_Init();
  HAL_Delay(20);

  memcpy(subMappingBody, subMappingHead, sizeof(subMappingHead));
  memcpy(subMappingBody + 4, subMappingArms, sizeof(subMappingArms));
  memcpy(subMappingBody + 4 + 3, subMappingLegs, sizeof(subMappingLegs));

  // Empty PWM buffer
  uint8_t pwmBuf[pwmLen];
  for(uint8_t i = 0; i < pwmLen; i++){
    pwmBuf[i] = 0;
  }

  // Switch to PWM Page
  ISSI_Switch_Page(commandPage1);

  // Clear LEDs
  ISSI_Write_Register(0x00, pwmBuf, pwmLen);

  // Fill Normals
  starSparkleNormalMap[subMappingStarsRed] = starBaseBrightRed;
  starSparkleNormalMap[subMappingStarsGreen] = starBaseBrightGreen;
  for(uint8_t i = 0; i < 2; i++){
      starSparkleNormalMap[subMappingStarsYellow[i]] = starBaseBrightYellow;
  }
  for(uint8_t i = 0; i < 3; i++){
      starSparkleNormalMap[subMappingStarsPink[i]] = starBaseBrightPink;
      starSparkleNormalMap[subMappingStarsCyan[i]] = starBaseBrightCyan;
  }
  for(uint8_t i = 0; i < 8; i++){
      starSparkleNormalMap[subMappingStarsWhite[i]] = starBaseBrightWhite;
  }

  while (1)
  {
    HAL_Delay(30);

    /* --------------------------- */
    /*         Star Sparkle        */
    if((noise8 >> 1) % 12 == 0){
      starSparkleMap[(noise8 / 14) % 18] = ((int8_t)(noise8 * noise16))/4;
    }
    for(uint8_t i = 0; i < 18; i++){
      starSparkleMap[i] -= starSparkleMap[i] > 0 ? 1 : 0;
      starSparkleMap[i] += starSparkleMap[i] < 0 ? 1 : 0;
    }
    for(uint8_t i = 0; i < 18; i++){
      pwmBuf[mappingStars[i]] = gammaMap[CLAMP(starSparkleNormalMap[i] + starSparkleMap[i], 0, 63)];
    }
    /* --------------------------- */

    /* --------------------------- */
    /*            Shork            */
    for(uint8_t i = 0; i < 4; i++){
      pwmBuf[mappingC[subMappingShark[i]]] = gammaMap[50];
      pwmBuf[mappingB[subMappingShark[i]]] = gammaMap[40];
    }
    pwmBuf[mappingC[subMappingShark[0]]] = gammaMap[20];
    pwmBuf[mappingP[subMappingShark[0]]] = gammaMap[10];
    pwmBuf[mappingR[subMappingShark[0]]] = gammaMap[30];
    pwmBuf[mappingG[subMappingShark[0]]] = gammaMap[40];
    /* --------------------------- */

    /* --------------------------- */
    /*            Body             */
    for(uint8_t i = 0; i < 15; i++){
      pwmBuf[mappingP[subMappingBody[i]]] = gammaMap[20];
      pwmBuf[mappingR[subMappingBody[i]]] = gammaMap[30];
      pwmBuf[mappingG[subMappingBody[i]]] = gammaMap[40];
      pwmBuf[mappingB[subMappingBody[i]]] = gammaMap[23];
    }
    for(uint8_t i = 0; i < 4; i++){
      pwmBuf[mappingP[subMappingHead[i]]] = gammaMap[0];
      pwmBuf[mappingR[subMappingHead[i]]] = gammaMap[20];
      pwmBuf[mappingG[subMappingHead[i]]] = gammaMap[20];
      pwmBuf[mappingB[subMappingHead[i]]] = gammaMap[5];
    }
    pwmBuf[mappingR[subMappingHead[2]]] = gammaMap[43];
    pwmBuf[mappingG[subMappingHead[2]]] = gammaMap[50];
    pwmBuf[mappingB[subMappingHead[2]]] = gammaMap[40];
    pwmBuf[mappingP[subMappingHead[2]]] = gammaMap[0];
    pwmBuf[mappingC[subMappingHead[2]]] = gammaMap[0];

    /* --------------------------- */

    /* --------------------------- */
    /*            Drink            */
    heartbeat = (uint8_t)ABS((int8_t)((HAL_GetTick() % 2560) / 10)) / 4;
    pwmBuf[mappingR[subMappingGlass]] = gammaMap[10];
    pwmBuf[mappingG[subMappingGlass]] = gammaMap[10];
    pwmBuf[mappingB[subMappingGlass]] = gammaMap[10];
    pwmBuf[mappingP[subMappingGlass]] = gammaMap[heartbeat+31];
    pwmBuf[mappingC[subMappingGlass]] = gammaMap[(32-heartbeat)+31];
    /* --------------------------- */

    /* --------------------------- */
    /*           Write FB          */
    ISSI_Write_Register(0x00, pwmBuf, pwmLen);
    /* --------------------------- */

  }
}

void rng(){
  noise32 += ((noise32 + 57) * (adc[2] + 123)) * 17 / 19;
  noise16 = (uint16_t)(noise32 * 19 / 7);
  noise16 ^= 0xAAAA;
  noise8 = (uint8_t)(noise32 * 23 / 11);
}

void SystemClock_Config(void)
{
  RCC_OscInitTypeDef RCC_OscInitStruct = {0};
  RCC_ClkInitTypeDef RCC_ClkInitStruct = {0};
  RCC_PeriphCLKInitTypeDef PeriphClkInit = {0};

  RCC_OscInitStruct.OscillatorType = RCC_OSCILLATORTYPE_HSI14|RCC_OSCILLATORTYPE_HSI48;
  RCC_OscInitStruct.HSI48State = RCC_HSI48_ON;
  RCC_OscInitStruct.HSI14State = RCC_HSI14_ON;
  RCC_OscInitStruct.HSI14CalibrationValue = 16;
  RCC_OscInitStruct.PLL.PLLState = RCC_PLL_NONE;
  HAL_RCC_OscConfig(&RCC_OscInitStruct);

  RCC_ClkInitStruct.ClockType = RCC_CLOCKTYPE_HCLK|RCC_CLOCKTYPE_SYSCLK
                              |RCC_CLOCKTYPE_PCLK1;
  RCC_ClkInitStruct.SYSCLKSource = RCC_SYSCLKSOURCE_HSI48;
  RCC_ClkInitStruct.AHBCLKDivider = RCC_SYSCLK_DIV1;
  RCC_ClkInitStruct.APB1CLKDivider = RCC_HCLK_DIV1;

  HAL_RCC_ClockConfig(&RCC_ClkInitStruct, FLASH_LATENCY_1);

  PeriphClkInit.PeriphClockSelection = RCC_PERIPHCLK_USB|RCC_PERIPHCLK_I2C1;
  PeriphClkInit.I2c1ClockSelection = RCC_I2C1CLKSOURCE_SYSCLK;
  PeriphClkInit.UsbClockSelection = RCC_USBCLKSOURCE_HSI48;

  HAL_RCCEx_PeriphCLKConfig(&PeriphClkInit);

}

static void MX_ADC_Init(void)
{
  ADC_ChannelConfTypeDef sConfig = {0};

  hadc.Instance = ADC1;
  hadc.Init.ClockPrescaler = ADC_CLOCK_ASYNC_DIV1;
  hadc.Init.Resolution = ADC_RESOLUTION_12B;
  hadc.Init.DataAlign = ADC_DATAALIGN_RIGHT;
  hadc.Init.ScanConvMode = ADC_SCAN_DIRECTION_FORWARD;
  hadc.Init.EOCSelection = ADC_EOC_SEQ_CONV;
  hadc.Init.LowPowerAutoWait = DISABLE;
  hadc.Init.LowPowerAutoPowerOff = DISABLE;
  hadc.Init.ContinuousConvMode = DISABLE;
  hadc.Init.DiscontinuousConvMode = DISABLE;
  hadc.Init.ExternalTrigConv = ADC_EXTERNALTRIGCONV_T1_TRGO;
  hadc.Init.ExternalTrigConvEdge = ADC_EXTERNALTRIGCONVEDGE_RISING;
  hadc.Init.DMAContinuousRequests = ENABLE;
  hadc.Init.Overrun = ADC_OVR_DATA_PRESERVED;
  HAL_ADC_Init(&hadc);

  sConfig.Channel = ADC_CHANNEL_0;
  sConfig.Rank = ADC_RANK_CHANNEL_NUMBER;
  sConfig.SamplingTime = ADC_SAMPLETIME_71CYCLES_5;
  HAL_ADC_ConfigChannel(&hadc, &sConfig);

  sConfig.Channel = ADC_CHANNEL_1;
  HAL_ADC_ConfigChannel(&hadc, &sConfig);

  sConfig.Channel = ADC_CHANNEL_TEMPSENSOR;
  HAL_ADC_ConfigChannel(&hadc, &sConfig);
}

static void MX_I2C1_Init(void)
{
  hi2c1.Instance = I2C1;
  hi2c1.Init.Timing = 0x2010091A;
  hi2c1.Init.OwnAddress1 = 0;
  hi2c1.Init.AddressingMode = I2C_ADDRESSINGMODE_7BIT;
  hi2c1.Init.DualAddressMode = I2C_DUALADDRESS_DISABLE;
  hi2c1.Init.OwnAddress2 = 0;
  hi2c1.Init.OwnAddress2Masks = I2C_OA2_NOMASK;
  hi2c1.Init.GeneralCallMode = I2C_GENERALCALL_DISABLE;
  hi2c1.Init.NoStretchMode = I2C_NOSTRETCH_DISABLE;
  HAL_I2C_Init(&hi2c1);

  HAL_I2CEx_ConfigAnalogFilter(&hi2c1, I2C_ANALOGFILTER_ENABLE);

  HAL_I2CEx_ConfigDigitalFilter(&hi2c1, 0);

  __HAL_SYSCFG_FASTMODEPLUS_ENABLE(I2C_FASTMODEPLUS_I2C1);
}

static void MX_TIM1_Init(void)
{
  TIM_ClockConfigTypeDef sClockSourceConfig = {0};
  TIM_MasterConfigTypeDef sMasterConfig = {0};

  htim1.Instance = TIM1;
  htim1.Init.Prescaler = 47;
  htim1.Init.CounterMode = TIM_COUNTERMODE_UP;
  htim1.Init.Period = 999;
  htim1.Init.ClockDivision = TIM_CLOCKDIVISION_DIV1;
  htim1.Init.RepetitionCounter = 0;
  htim1.Init.AutoReloadPreload = TIM_AUTORELOAD_PRELOAD_ENABLE;
  HAL_TIM_Base_Init(&htim1);

  sClockSourceConfig.ClockSource = TIM_CLOCKSOURCE_INTERNAL;
  HAL_TIM_ConfigClockSource(&htim1, &sClockSourceConfig);

  sMasterConfig.MasterOutputTrigger = TIM_TRGO_UPDATE;
  sMasterConfig.MasterSlaveMode = TIM_MASTERSLAVEMODE_DISABLE;
  HAL_TIMEx_MasterConfigSynchronization(&htim1, &sMasterConfig);
}

static void MX_DMA_Init(void)
{
  __HAL_RCC_DMA1_CLK_ENABLE();

  HAL_NVIC_SetPriority(DMA1_Channel1_IRQn, 0, 0);
  HAL_NVIC_EnableIRQ(DMA1_Channel1_IRQn);
  HAL_NVIC_SetPriority(DMA1_Channel2_3_IRQn, 0, 0);
  HAL_NVIC_EnableIRQ(DMA1_Channel2_3_IRQn);
}

static void MX_GPIO_Init(void)
{
  GPIO_InitTypeDef GPIO_InitStruct = {0};

  __HAL_RCC_GPIOA_CLK_ENABLE();
  __HAL_RCC_GPIOB_CLK_ENABLE();

  HAL_GPIO_WritePin(EN_GPIO_Port, EN_Pin, GPIO_PIN_RESET);

  GPIO_InitStruct.Pin = INT_Pin;
  GPIO_InitStruct.Mode = GPIO_MODE_IT_RISING;
  GPIO_InitStruct.Pull = GPIO_NOPULL;
  HAL_GPIO_Init(INT_GPIO_Port, &GPIO_InitStruct);

  GPIO_InitStruct.Pin = EN_Pin;
  GPIO_InitStruct.Mode = GPIO_MODE_OUTPUT_PP;
  GPIO_InitStruct.Pull = GPIO_NOPULL;
  GPIO_InitStruct.Speed = GPIO_SPEED_FREQ_LOW;
  HAL_GPIO_Init(EN_GPIO_Port, &GPIO_InitStruct);
}

void Error_Handler(void)
{
  __disable_irq();
  while (1)
  {
  }
}

#ifdef  USE_FULL_ASSERT

void assert_failed(uint8_t *file, uint32_t line)
{

}
#endif

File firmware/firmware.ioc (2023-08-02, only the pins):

Mcu.UserName=STM32F072C8Tx
PA0.GPIO_Label=NTC1
PA0.Signal=ADC_IN0
PA1.GPIO_Label=NTC0
PA1.Signal=ADC_IN1
PA11.Signal=USB_DM
PA12.Signal=USB_DP
PA13.Signal=SYS_SWDIO
PA14.Signal=SYS_SWCLK
PB13.GPIO_Label=INT
PB13.Signal=GPXTI13
PB14.GPIO_Label=EN
PB14.Signal=GPIO_Output
PB6.Signal=I2C1_SCL
PB7.Signal=I2C1_SDA

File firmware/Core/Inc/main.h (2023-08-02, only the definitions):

#define NTC1_Pin GPIO_PIN_0
#define NTC1_GPIO_Port GPIOA
#define NTC0_Pin GPIO_PIN_1
#define NTC0_GPIO_Port GPIOA
#define INT_Pin GPIO_PIN_13
#define INT_GPIO_Port GPIOB
#define EN_Pin GPIO_PIN_14
#define EN_GPIO_Port GPIOB

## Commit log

2021-10-21 added backboard
    [coaster_backboard.kicad_pcb, coaster_backboard.sch]
2021-10-21 added frontboard
    [coaster_frontboard.kicad_pcb, coaster_frontboard.sch]
2021-10-21 added midboard
    [coaster_frontboard.kicad_pcb, coaster_frontboard.sch]
2021-10-21 routing 80%
    [coaster_backboard.kicad_pcb, coaster_backboard.sch]
2023-04-21 updated hw
    [coaster_backboard.kicad_pcb, coaster_backboard.kicad_sch, coaster_backboard.sch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]
2023-04-21 updated midboard
    [coaster_frontboard.kicad_pcb, coaster_frontboard.sch]
2023-08-02 updated backboard
    [coaster_backboard.kicad_pcb, coaster_backboard.kicad_sch, coaster_backboard.sch]
2023-08-02 updated frontboard
    [coaster_frontboard.kicad_pcb, coaster_frontboard.kicad_sch, coaster_frontboard.sch]
2023-09-30 added schematic print
2025-04-08 updated schematic
    [coaster_backboard.kicad_pcb, coaster_backboard.kicad_sch]

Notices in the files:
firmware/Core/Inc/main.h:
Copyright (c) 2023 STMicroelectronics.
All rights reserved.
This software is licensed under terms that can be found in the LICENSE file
